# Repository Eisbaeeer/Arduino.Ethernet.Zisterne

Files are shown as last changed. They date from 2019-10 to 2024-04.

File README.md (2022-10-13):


# Arduino.Ethernet.Zisterne

## Beschreibung
Dieses Projekt ermöglicht eine Füllstandsmessung per Pegelsonde.
Zur Verwendung kommt ein Arduino Nano, ein W5100 Ethernet Shield, 
ein 4-20mA Stromwandler und ein 4x16 Zeichen LCD mit I2C Schnittstelle.

Die Meßdaten werden per MQTT an einen Server übertragen und auf dem Display angezeigt.

In der ino Datei müssen noch entsprechende Anpassungen gemacht werden.
Diese sind am Anfang des Codes.

- Volumen der Zisterne    
- Dichte des Mediums   
- Analog Wert der Kalibrierung
- IP-Adresse des MQTT Servers   
- Port des MQTT Servers   
- MQTT Benutzername   
- MQTT Passwort   
- IP-Adresse des Nano (falls kein DHCP zur Verfügung steht)   
- MAC-Adresse des Nano (W5100)  

## Verschaltung der Module
Ich verwende Standard Module, welche über das Internet verfügbar sind. Die Klemmblöcke habe ich ausgelötet und durch Stifte erstetzt.
Als Basis verwende ich eine Lochraster Platine. Damit sind alle Baugruppen schnell ersetzbar.
Grundsätzlich ist im Sketch schon beschrieben, welche Ports verwendung finden. Ich habe als Hilfestellung meine Verdrahtung hinzugefügt.   



## Abgleich
Bitte erst ganz durchlesen!
1. Aufstecken der ersten Baugruppe (Step-up Wandler, Modul ganz unten) und anlegen der 5V Eingangsspannung. Mit Multimeter an VOUT+ und VOUT- messen und mit dem Poti maximal 24V einstellen.   
2. Spannung an den Schraubklemmen Drucksensor messen. Max. 24V (je nach Sonde. Bitte Datenblatt der Sonde lesen)   
3. Wandlermodul aufstecken (oberes Modul unterhalb der Platine mit den 2 blauen Potis) und die Jumper J1 und J2 abziehen.   
4. Pegelsonde anschließen   
5. Linker Poti stellt Nullpunkt ein. Dazu mit Multimeter an hellblau (mittlerer Pin vom Wandlermodul) auf 0V einstellen. Es kann auch ein negativer Wert angezeigt werden. Das Poti macht locker 20 Umdrehungen, bis es von min auf max geht.   
6. Rechter Poti stellt dann den Range ein. Minimum ist bei Tank leer, maximum bei Tank voll (maximum darf 3.3V nicht übersteigen!   
7. Jetzt darf erst das Nano Modul mit dem Ethernetshield aufgesteckt werden. Bitte jedes Modul nur dann aufstecken, wenn die Schaltung spannungsfrei ist. Also erst ausschalten, dann aufstecken.   
8. Eventuell im Sketch noch den maximalen analogen Wert anpassen, falls der nicht stimmt. Der Meßwert wird auf der seriellen Konsole ausgegeben oder an der LCD angezeigt. (Hinweis: man benötigt nicht unbedingt eine LCD Anzeige).   

## Changelog

### 1.6
- (20221013 Eisbaeeer)
- Portierung von Arduino IDE zu Platformio
- Code aufgeräumt
- Doppel Deklarationen entfernt
- Verbesserung der Ethernet Initialisierung
- Ausgabe der IP auf dem Display

### 1.5
- (20200528 ltathome)
- Erweiterung MQTT für die Steuerung eines Relais für die Frischwasser Nachspeisung bzw. Umschaltung   
- Grenzwerte über MQTT einstellbar   
- Umschaltung Betriebsart über Taster Pin2 möglich   

### 1.4
- (20200110 Eisbaeeer)   
- Array zur Beruhigung des Messwertes hinzugfügt   

### 1.3
- (20191028 Eisbaeeer)   
- MQTT Port ist jetzt konfigurierbar
- MQTT Authentifizierung 

### 1.2
- (20191019 Eisbaeeer)   
- LCD wechselt jetzt alle 30 Sek. zwischen Uptime und Analog Messwert   
- (20191024 Eisbaeeer)
- Fixed update_d in MQTT

### 1.1
- (20191019 Eisbaeeer)   
- Dichte Berechnung hinzugefügt   

### 1.0
- (Eisbaeeer)
Initial Version

## License
The MIT License (MIT)
Copyright (c) 2019 Eisbaeeer <eisbaeeer@gmail.com>

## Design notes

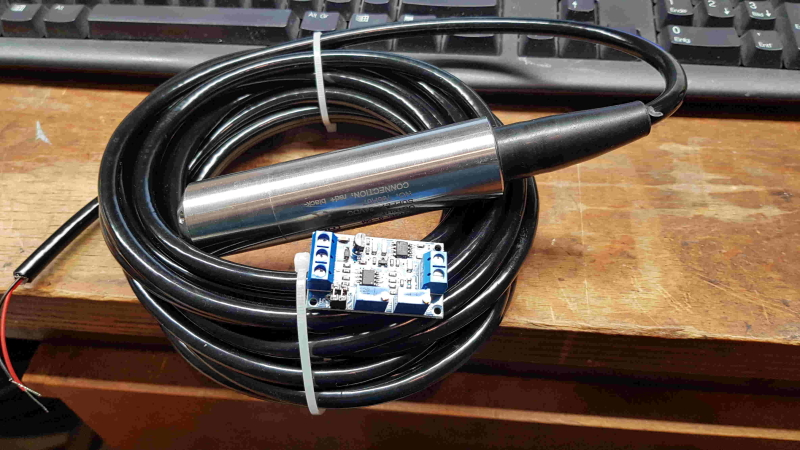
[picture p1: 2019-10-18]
Pics/Drucksonde.png

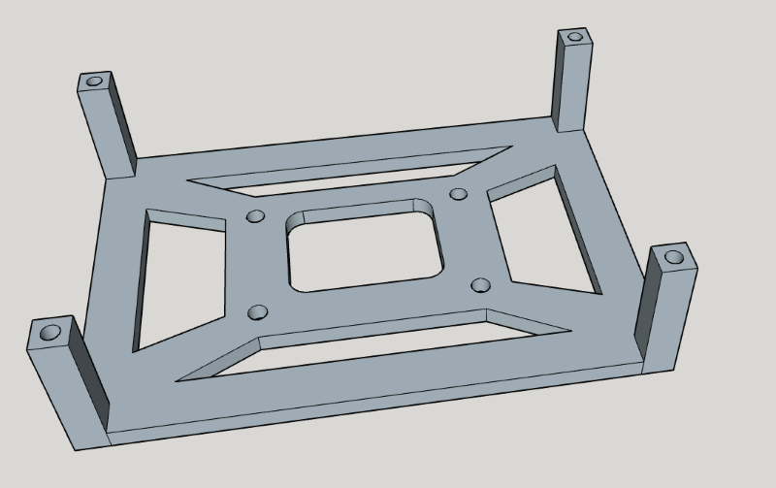
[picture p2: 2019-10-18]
Pics/DIN-Halter-Display-16x4.png

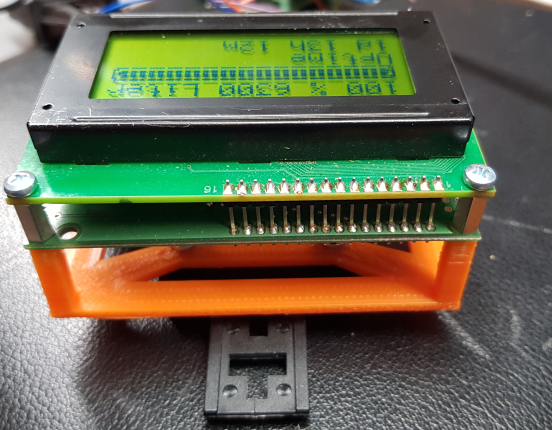
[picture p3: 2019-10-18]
Pics/DIN-Halter1.png

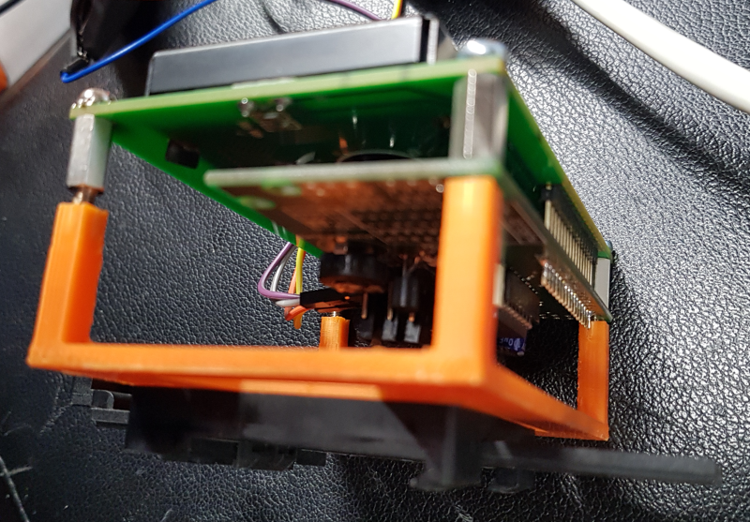
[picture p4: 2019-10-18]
Pics/DIN-Halter2.png

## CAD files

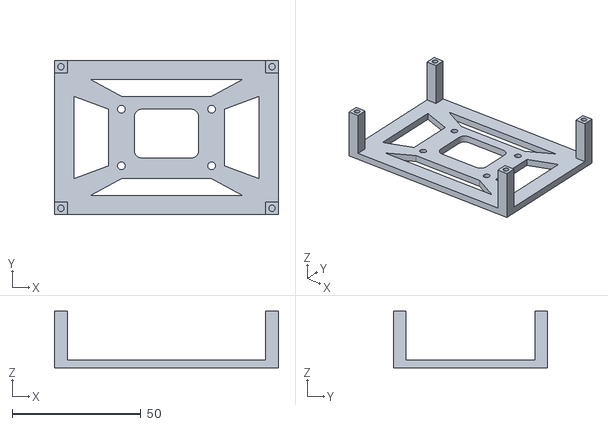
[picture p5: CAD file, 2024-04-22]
stl/LCD-Halter-Hutschhiene.stl
87.0 x 60.0 x 22.0

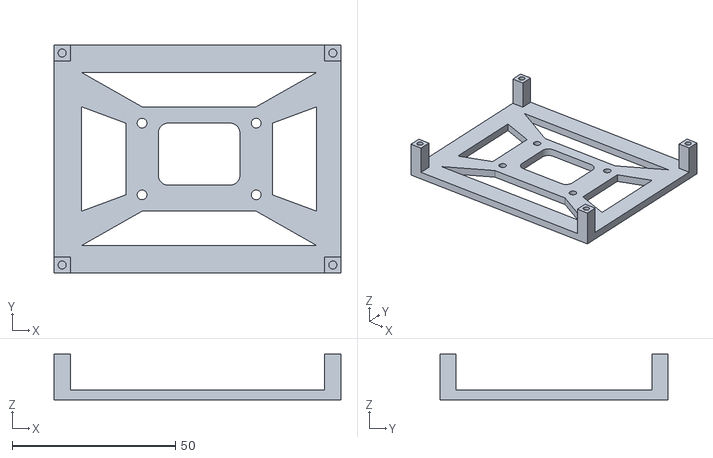
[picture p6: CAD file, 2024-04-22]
stl/Nano-Halter-Hutschhiene.stl
88.0 x 70.0 x 14.0

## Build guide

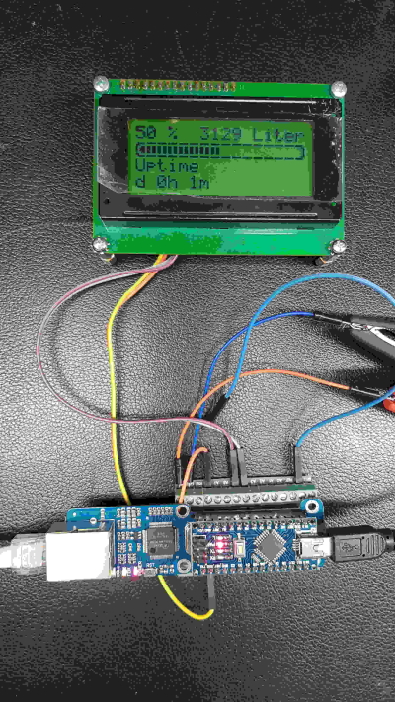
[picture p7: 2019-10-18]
Pics/Testaufbau.png

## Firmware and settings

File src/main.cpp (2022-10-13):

#include <Arduino.h>

/*------------------------------------------------------------------------------------------------------------------------------------------------------------------
  Program:      Füllstandsmessung mit Pegelsonde

  Description:  Dieses Programm misst die analolge Spannung an einem Port, welche von einem Drucksensor
                0-5m Meßhöhe und 4-20mA Stromschnittstelle erzeugt wird.
                Voraussetzung ist ein Meßwandler, welcher die 24V Versorgungsspannung an
                den Drucksensor liefert und 0-3,3V analoge Spannung ausgibt.
                Dienste:
                DHCP, wenn vorhanden, sonst wird eine feste IP mit 192.168.1.21 vergeben.
                  
  Hardware:     Arduino Nano ATmega 328P 
                W5100 Netzwerk shield
                LCD Display I2C HD44780
				
				Pin-Ports:
				A0 = Analog IN
				A4 = SDA
				A5 = SCL
				
  
  Date:         20191013
  Modified:     Initial Version 1.0
                - DHCP error routine

                20191017
                - Fixed uptime_d

                20191019
                Version 1.1
                - Dichte Berechnung hinzugefügt
                Version 1.2
                - LCD wechselt jetzt alle 30 Sek. zwischen Uptime und Analog Messwert

                20191024
                - Fixed MQTT uptime_d char array

                20191028
                Version 1.3
                - MQTT Port definierbar
                - MQTT User Password authentication
				
				20200110
				Version 1.4
				- Array für die Beruhigung des Messwertes eingefügt

        20200528 (ltathome)
        Version 1.5
        - Erweiterung MQTT für die Steuerung eines Relais für die Frischwasser Nachspeisung bzw. Umschaltung
        - Grenzwerte über MQTT einstellbar
        - Umschaltung Betriebsart über Taster Pin2 möglich

  Author:       Eisbaeeer, https://github.com/Eisbaeeer               
 
  Author:       Ethernet part: W.A. Smith, http://startingelectronics.com
                progress bar -  CC BY-SA 3.0 :  skywodd, https://www.carnetdumaker.net/articles/faire-une-barre-de-progression-avec-arduino-et-liquidcrystal/
                ltathome fixes + parameter level switch
				
  LICENSE: 		MIT License
  
-------------------------------------------------------------------------------------------------------------------------------------------------------------------*/
// Include some libraries
#include <Ethernet.h>
#include <SPI.h>

#include <Wire.h>
#include <hd44780.h>                       // main hd44780 header
#include <hd44780ioClass/hd44780_I2Cexp.h> // i2c expander i/o class header
hd44780_I2Cexp lcd; // declare lcd object: auto locate & auto config expander chip
#include <Wire.h> 
#include <LiquidCrystal_I2C.h>
const int LCD_COLS = 16;
const int LCD_ROWS = 4;
const int LCD_NB_COLUMNS = 16;

#include "progress.h"
#include <PubSubClient.h>



// ##############################################################################################################################
// ---- HIER die Anpassungen vornehmen ----
// ##############################################################################################################################
// Hier die maximale Füllmenge des Behälters angeben. Dies gilt nur für symmetrische Behälter.
const float max_liter = 6300;                           

// Analoger Wert bei maximalem Füllstand (wird alle 30 Sekungen auf dem LCD angezeigt oder in der seriellen Konsole mit 9600 Baud.
const int analog_max = 763;                           

// Dichte der Flüssigkeit - Bei Heizöl bitte "1.086" eintragen, aber nur wenn die Kalibrierung mit Wasser erfolgt ist! 
// Bei Kalibrierung mit Wasser bitte "1.0" eintragen
const float dichte = 1.0;                              

// IP Adresse und Port des MQTT Servers
IPAddress mqttserver(192, 168, 1, 200);
const int mqttport = 1883;
// Wenn der MQTT Server eine Authentifizierung verlangt, bitte folgende Zeile aktivieren und Benutzer / Passwort eintragen
#define mqttauth

char *mqttuser = const_cast<char*>("MQTT ID");
char *mqttpass = const_cast<char*>("MQTTPASS");                 

// IP Adresse, falls kein DHCP vorhanden ist. Diese Adresse wird nur verwendet, wenn der DHCP-Server nicht erreichbar ist.
IPAddress ip(192, 168, 1, 203);   
IPAddress myDns(192, 168, 1, 1);                       

// MAC-Addresse bitte anpassen! Sollte auf dem Netzwerkmodul stehen. Ansonsten eine generieren.
byte mac[] = { 0xDE, 0xAD, 0xBE, 0xEF, 0xFE, 0x0A };    

// ##############################################################################################################################
// AB hier nichts mehr ändern!
// (Ausser ihr wisst, was ihr tut)
// ##############################################################################################################################

char buf[40];
#define MODE_PIN 2
#define MODE_ZISTERNE 0
#define MODE_HAUSWASSER 1
#define MODE_AUTO 2
#define MODE_COUNT 10
bool setmode = false;
const char *modes[] = {"Zisterne", "Hauswasser", "Auto"};
int mode_count = MODE_COUNT;
int mode = MODE_AUTO;
int old_mode = MODE_AUTO;
int pin_stat;
int old_stat;

#define VALVE_PIN 3
#define VALVE_ZISTERNE LOW
#define VALVE_HAUSWASSER HIGH
int valve = VALVE_ZISTERNE;
int new_valve = VALVE_ZISTERNE;
int reason = 0;
const char *valves[] = {"Zisterne", "Hauswasser"};
const char *reasons[] = {"manuelle Steuerung", "Automatik voll", "Automatik leer"};
 
#define USE_SERIAL Serial

// No more delay
unsigned long startMillis;  // some global variables available anywhere in the program
unsigned long currentMillis;
const unsigned long sekunde = 1000;  // one seconds

unsigned long pinMillis;
unsigned long lastMillis = 0;

int secs = 0, mins = 0, hours = 0, days = 0;
char uptime[25];

float percent;
float liter;
float limit_low = 500;
float limit_high = 1000;
boolean LCD_Page;

// Analog IN
const int analogPin = A0;
const int messungen = 60;     // Anzahl Messungen
int myArray[messungen];       // Array für Messwerte
float analog = 0.0;             // Durchschnittswert
int pointer = 0;              // Pointer für Messung

// MQTT global vars
unsigned int send_interval = 10; // the sending interval of indications to the server, by default 10 seconds

boolean mqttconnected = false;

// MQTT definitions
void MqttCallback(char *topic, byte *payload, unsigned int length);
EthernetClient ethClient;
PubSubClient mqttclient;
#define MQTT_ID "Zisterne"
char pl[30];

void MqttConnect(char *user, char* pass) {

    mqttclient.setClient(ethClient);
    mqttclient.setServer(mqttserver, mqttport);
    mqttclient.setCallback(MqttCallback);
    
    mqttconnected = mqttclient.connect(MQTT_ID, user, pass);
    if (mqttconnected) {
        // USE_SERIAL.println("Connected to Mqtt-Server");
        mqttclient.subscribe("Zisterne/cmnd/Mode");
        mqttclient.subscribe("Zisterne/cmnd/Limit");
        mqttclient.subscribe("Zisterne/Mode");
        // USE_SERIAL.println("subscribing to Zisterne/cmnd/Mode");
    }
}

void Mqttpublish(void) {
    if (mqttclient.connected()) {
        dtostrf(analog, 5, 2, buf);
        mqttclient.publish("Zisterne/Analog", buf);
        dtostrf(liter, 5, 0, buf);
        mqttclient.publish("Zisterne/Liter", buf);
        dtostrf(limit_low, 1, 0, buf);
        mqttclient.publish("Zisterne/LiterLow", buf);
        dtostrf(limit_high, 1, 0, buf);
        mqttclient.publish("Zisterne/LiterHigh", buf);
        dtostrf(percent, 5, 0, buf);
        mqttclient.publish("Zisterne/Prozent", buf);
        if (mode == 2) {
            mqttclient.publish("Zisterne/Modus", "Auto");
        } else {
            mqttclient.publish("Zisterne/Modus", "Manuell");          
        }
        dtostrf(mode, 1, 0, buf);
        mqttclient.publish("Zisterne/Mode", buf);
        dtostrf(valve, 1, 0, buf);
        mqttclient.publish("Zisterne/Valve", buf);
        mqttclient.publish("Zisterne/Ventil", valves[valve]);
        mqttclient.publish("Zisterne/Uptime", uptime);
    } else {
        MqttConnect(mqttuser, mqttpass);  
    }
}
 

void Uptime() {
    secs++;
    secs = secs % 60;
    if (secs == 0) {
        mins++;
        mins = mins % 60;
        if (mins == 0) {
            hours++;
            hours = hours % 24;
            if (hours == 0) {
                days++;
                days = days % 10000;   // Nach 9999 Tagen zurück auf 0 (das sind 27 Jahre....)
            }
        }
    }
    sprintf(uptime, "%4dd %2dh %2dm", days, hours, mins);
  
    if (secs == 0) {        // Every Minute
        //USE_SERIAL.print(F("Uptime: "));
        //USE_SERIAL.println(uptime);
        // MQTT reconnect timeout
        //Mqttpublish();
    }
    if (secs % send_interval == 0) { // Alle 30 Sekunden
        LCD_Page = !LCD_Page;
        Mqttpublish();
        // MqttSub();
    }
    if (mins == 0 && secs == 0) {      // Jede Stunde
        //USE_SERIAL.println(F("ONE HOUR"));
    }
}

void ReadAnalog() {
    // read the analog value and build floating middle
    myArray[pointer++] = analogRead(analogPin);      // read the input pin
    // myArray[pointer++] = 352;
 
    pointer = pointer % messungen;

    // Werte aufaddieren
    for (int i = 0; i < messungen; i++) {
        analog = analog + myArray[i];
  }
    // Summe durch Anzahl - geglättet
    analog = analog / messungen;
 
    percent = min(100 * analog / analog_max, 100);
    float calc = max_liter / analog_max;      // calculate percent
    calc = calc * dichte;                     // calculate dichte
    liter = min(analog * calc, max_liter);    // calculate liter
}

void setup()
{
  USE_SERIAL.begin(9600);       // for debugging

/*--------------------------------------------------------------
 * LCD init
--------------------------------------------------------------*/
  lcd.init();
  int status;
  status = lcd.begin(LCD_COLS, LCD_ROWS);
  if(status) // non zero status means it was unsuccesful
  {
    status = -status; // convert negative status value to positive number
    // begin() failed so blink error code using the onboard LED if possible
    hd44780::fatalError(status); // does not return
  }

  // initalization was successful, the backlight should be on now
  // Print a message to the LCD
  lcd.print("Zisterne");
  lcd.setCursor(0, 1);
  lcd.print("Version 1.6");
  lcd.setCursor(0, 3);
  lcd.print("github/Eisbaeeer");
  delay(2000);
  setup_progressbar();

/*--------------------------------------------------------------  
 * Milliseconds start
--------------------------------------------------------------*/
  startMillis = millis();  //initial start time

/*--------------------------------------------------------------  
 * Ethernet init
--------------------------------------------------------------*/ 
    lcd.clear();  
    if (Ethernet.begin(mac) == 0) {
    //Serial.println("Failed to configure Ethernet using DHCP");
    // Check for Ethernet hardware present
    lcd.setCursor(0, 0);
    lcd.print("no DHCP");
    if (Ethernet.hardwareStatus() == EthernetNoHardware) {
      //Serial.println("Ethernet shield was not found.  Sorry, can't run without hardware. :(");
      //lcd.setCursor(0, 0);
      //lcd.print("no Hardware");
      while (true) {
        delay(1); // do nothing, no point running without Ethernet hardware
      }
    }
    if (Ethernet.linkStatus() == LinkOFF) {
      //Serial.println("Ethernet cable is not connected.");
      lcd.setCursor(0, 0);
      lcd.print("no Cable");
    }
    // try to configure using IP address instead of DHCP:
    Ethernet.begin(mac, ip, myDns);
  } else {
    //Serial.print("  DHCP assigned IP ");
    //Serial.println(Ethernet.localIP());
        //lcd.setCursor(0, 0);
        //lcd.print("IP-Address");
        lcd.setCursor(0, 0);
        lcd.print(Ethernet.localIP());
  }

  delay(5000);

     // start MQTT client
    MqttConnect(mqttuser, mqttpass);  

    /*-------------------------------------------------------------------
     * Setup Pins for Valve and mode-setting
     */
    pinMode(MODE_PIN, INPUT_PULLUP);
    pinMode(VALVE_PIN, OUTPUT);
  
    pin_stat = old_stat = digitalRead(MODE_PIN);
}



void MqttCallback(char *topic, byte *payload, unsigned int length) {
    char *payloadvalue;
    char *payloadkey;

    payload[length] = '\0';
    payloadkey = (char *)&payload[0];

    // USE_SERIAL.println(payloadstring);
    if (strcmp(topic, "Zisterne/cmnd/Mode") == 0 || strcmp(topic, "Zisterne/Mode") == 0) {
        if (strcmp(payloadkey, "0") == 0 || strcmp(payloadkey, "Zisterne") == 0) {
            mode = MODE_ZISTERNE;
        } else if (strcmp(payloadkey, "1") == 0 || strcmp(payloadkey, "Hauswasser") == 0) {
            mode = MODE_HAUSWASSER;
        } else if (strcmp(payloadkey, "2") == 0 || strcmp(payloadkey, "Auto") == 0) {
            mode = MODE_AUTO;
        }
    } else if (strcmp(topic, "Zisterne/cmnd/Limit") == 0) {
        int eq = 0;
        for (unsigned int i = 0; i < length; i++) {
            if (payload[i] == '=') {
                eq = i;
                break;
            }
        }
        if (eq > 0) {
            payload[eq++] = 0;
            payloadvalue = (char *)&payload[eq];
            if (strcmp((char *)payload, "Low") == 0 || strcmp((char *)payload, "low") == 0) {
                limit_low = atoi(payloadvalue);
            }
            if (strcmp((char *)payload, "High") == 0 || strcmp((char *)payload, "high") == 0) {
                limit_high = atoi(payloadvalue);
            }
        }
    }
}

void draw_progressbar(byte percent) {
 
  lcd.clear(); 
  /* Affiche la nouvelle valeur sous forme numérique sur la première ligne */
  lcd.setCursor(0, 0);
  lcd.print(percent);
  lcd.print(F(" %  ")); 
  // N.B. Les deux espaces en fin de ligne permettent d'effacer les chiffres du pourcentage
  // précédent quand on passe d'une valeur à deux ou trois chiffres à une valeur à deux ou un chiffres.
 
  /* Déplace le curseur sur la seconde ligne */
  lcd.setCursor(0, 1);
 
  /* Map la plage (0 ~ 100) vers la plage (0 ~ LCD_NB_COLUMNS * 2 - 2) */
  byte nb_columns = map(percent, 0, 100, 0, LCD_NB_COLUMNS * 2 - 2);
  // Chaque caractère affiche 2 barres verticales, mais le premier et dernier caractère n'en affiche qu'une.

  /* Dessine chaque caractère de la ligne */
  for (byte i = 0; i < LCD_NB_COLUMNS; ++i) {

    if (i == 0) { // Premiére case

      /* Affiche le char de début en fonction du nombre de colonnes */
      if (nb_columns > 0) {
        lcd.write(1); // Char début 1 / 1
        nb_columns -= 1;

      } else {
        lcd.write((byte) 0); // Char début 0 / 1
      }

    } else if (i == LCD_NB_COLUMNS -1) { // Derniére case

      /* Affiche le char de fin en fonction du nombre de colonnes */
      if (nb_columns > 0) {
        lcd.write(6); // Char fin 1 / 1

      } else {
        lcd.write(5); // Char fin 0 / 1
      }

    } else { // Autres cases

      /* Affiche le char adéquat en fonction du nombre de colonnes */
      if (nb_columns >= 2) {
        lcd.write(4); // Char div 2 / 2
        nb_columns -= 2;

      } else if (nb_columns == 1) {
        lcd.write(3); // Char div 1 / 2
        nb_columns -= 1;

      } else {
        lcd.write(2); // Char div 0 / 2
      }
    }
  }
}

void write_lcd(void)
{
    char LCDbuff[20];

if (!setmode) {
    // Zeile 1
    lcd.setCursor(6, 0); 
    dtostrf(liter, 4, 0, LCDbuff);
    lcd.print(LCDbuff); lcd.print(" Liter");
    
    if ( LCD_Page == false ) {
              // Zeile 3
              lcd.setCursor(0, 2); 
              lcd.print("Uptime");

              // Zeile 4
              lcd.setCursor(0, 3);
              lcd.print(uptime);
    } else {
              // Zeile 3
              lcd.setCursor(0, 2); 
              lcd.print("Messwert Analog");

              // Zeile 4
              lcd.setCursor(0, 3);
              lcd.print(analogRead(analogPin));    
              
    }
 
 }
}

void loop()
{
    /*--------------------------------------------------------------
     remove delay (half second)
     --------------------------------------------------------------*/
  
    pin_stat = digitalRead(MODE_PIN);
    pinMillis = millis();
    if (pin_stat == LOW) {
        if (pinMillis - lastMillis > 200) {
            //USE_SERIAL.println("Impuls Low");
            lastMillis = pinMillis;
            mode_count = MODE_COUNT;
            if (!setmode) {
                setmode = true;
                old_mode = mode;
                //sprintf(buf, "Enter Settings-Mode %d (%s)", mode, modes[mode]);
                //USE_SERIAL.println(buf);
            } else {
                mode--;
                if (mode < 0) {
                    mode = 2;
                }
                //sprintf(buf, "Mode change to %d (%s)", mode, modes[mode]);
                //USE_SERIAL.println(buf);
            }
        }
    }

/*--------------------------------------------------------------  
 * remove delay (one second)
--------------------------------------------------------------*/
  currentMillis = millis();  //get the current "time" (actually the number of milliseconds since the program started)
    if (currentMillis - startMillis >= sekunde) { // Hier eine Sekunde warten
        mqttclient.loop();
  startMillis = currentMillis;

    /******************************************************************************************
   *  1 Sekunden Takt 
   * *****************************************************************************************
   *  
   *  
   *******************************************************************************************/
    
    // Hier die Funktionen im Sekundentakt
    // ###################################    
      
        Uptime();
        ReadAnalog();
        
        if (setmode) {
            mode_count--;
            if (mode_count <= 0) {
                //sprintf(buf, "leaving Settings-Mode - change from %d to %d (%s)", old_mode, mode, modes[mode]);
                //USE_SERIAL.println(buf);
                old_mode = mode;
                setmode = false;
            }
        }
        if (!setmode) {
            if (mode == MODE_ZISTERNE) {
                new_valve = VALVE_ZISTERNE;
                reason = 0;
            } else if (mode == MODE_HAUSWASSER) {
                new_valve = VALVE_HAUSWASSER;
                reason = 0;
            } else if (mode == MODE_AUTO) {
                if (liter >= limit_high) {
                    new_valve = VALVE_ZISTERNE;
                    reason = 1;
                }
                if (liter <= limit_low) {
                    new_valve = VALVE_HAUSWASSER;
                    reason = 2;
        }
        
  
    }

        /*-----------------------------------------------------------
         * Wenn Ventil umzuschalten ist
        */
        if (new_valve != valve) {
            valve = new_valve;
            digitalWrite(VALVE_PIN, valve);
            //sprintf(buf, "Set Valve to %s (%s)", valves[valve], reasons[reason]);
            //USE_SERIAL.println(buf);
     }

        if (!setmode) {
            draw_progressbar(percent);

      }   
    }
write_lcd();      
 }
}
   /******************************************************************************************
   *  Ende Loop
   * ****************************************************************************************/

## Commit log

2019-10-28 Version 1.3
    Schaltplan und Abgleich hinzugefügt
2020-01-10 Version 1.4
    Array zur Beruhigung des Messwertes hinzugefügt.
2024-04-22 Added STL
    Added folder stl and stl´s.
    [LCD-Halter-Hutschhiene.stl, Nano-Halter-Hutschhiene.stl]
